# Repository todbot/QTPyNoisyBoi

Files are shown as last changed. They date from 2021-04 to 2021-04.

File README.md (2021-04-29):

# QTPyNoisyBoi

## QTPy/XIAO-based noisy 3-channel CV modulator Eurorack synth module

This is a bad idea.

It has:
- 3 CV outputs
- 1 gate input
- 3 knobs (next to outputs)
- 3 Neopixels (next to outputs)
- 2 tap buttons
- 1 neopixel on QT Py

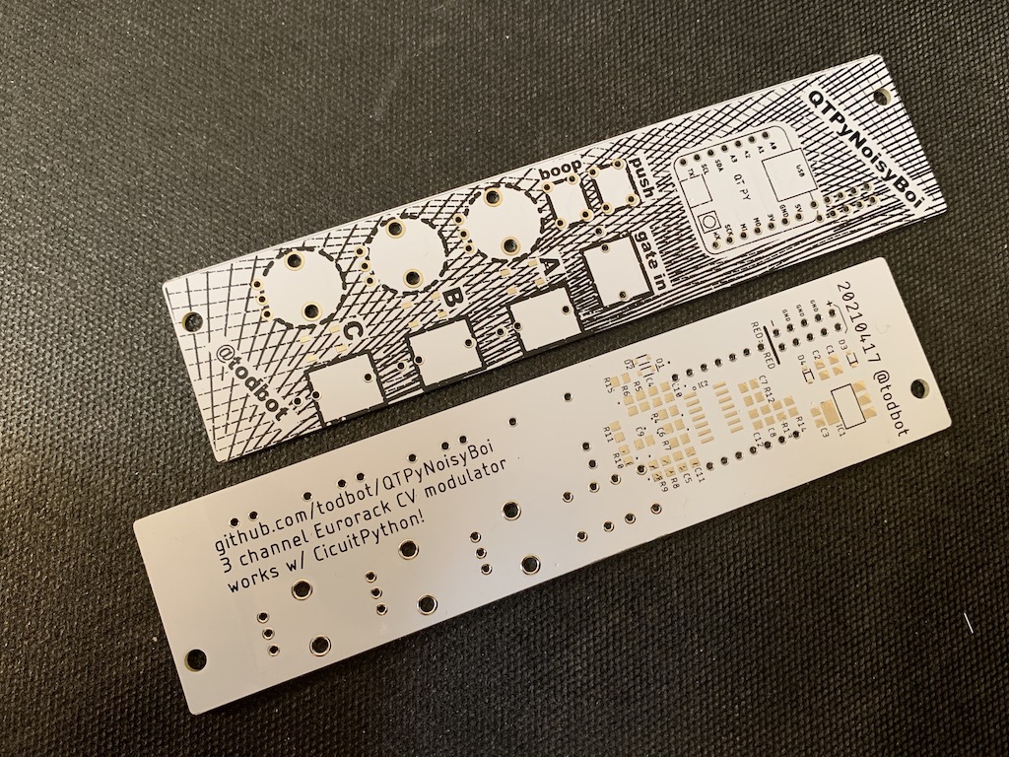
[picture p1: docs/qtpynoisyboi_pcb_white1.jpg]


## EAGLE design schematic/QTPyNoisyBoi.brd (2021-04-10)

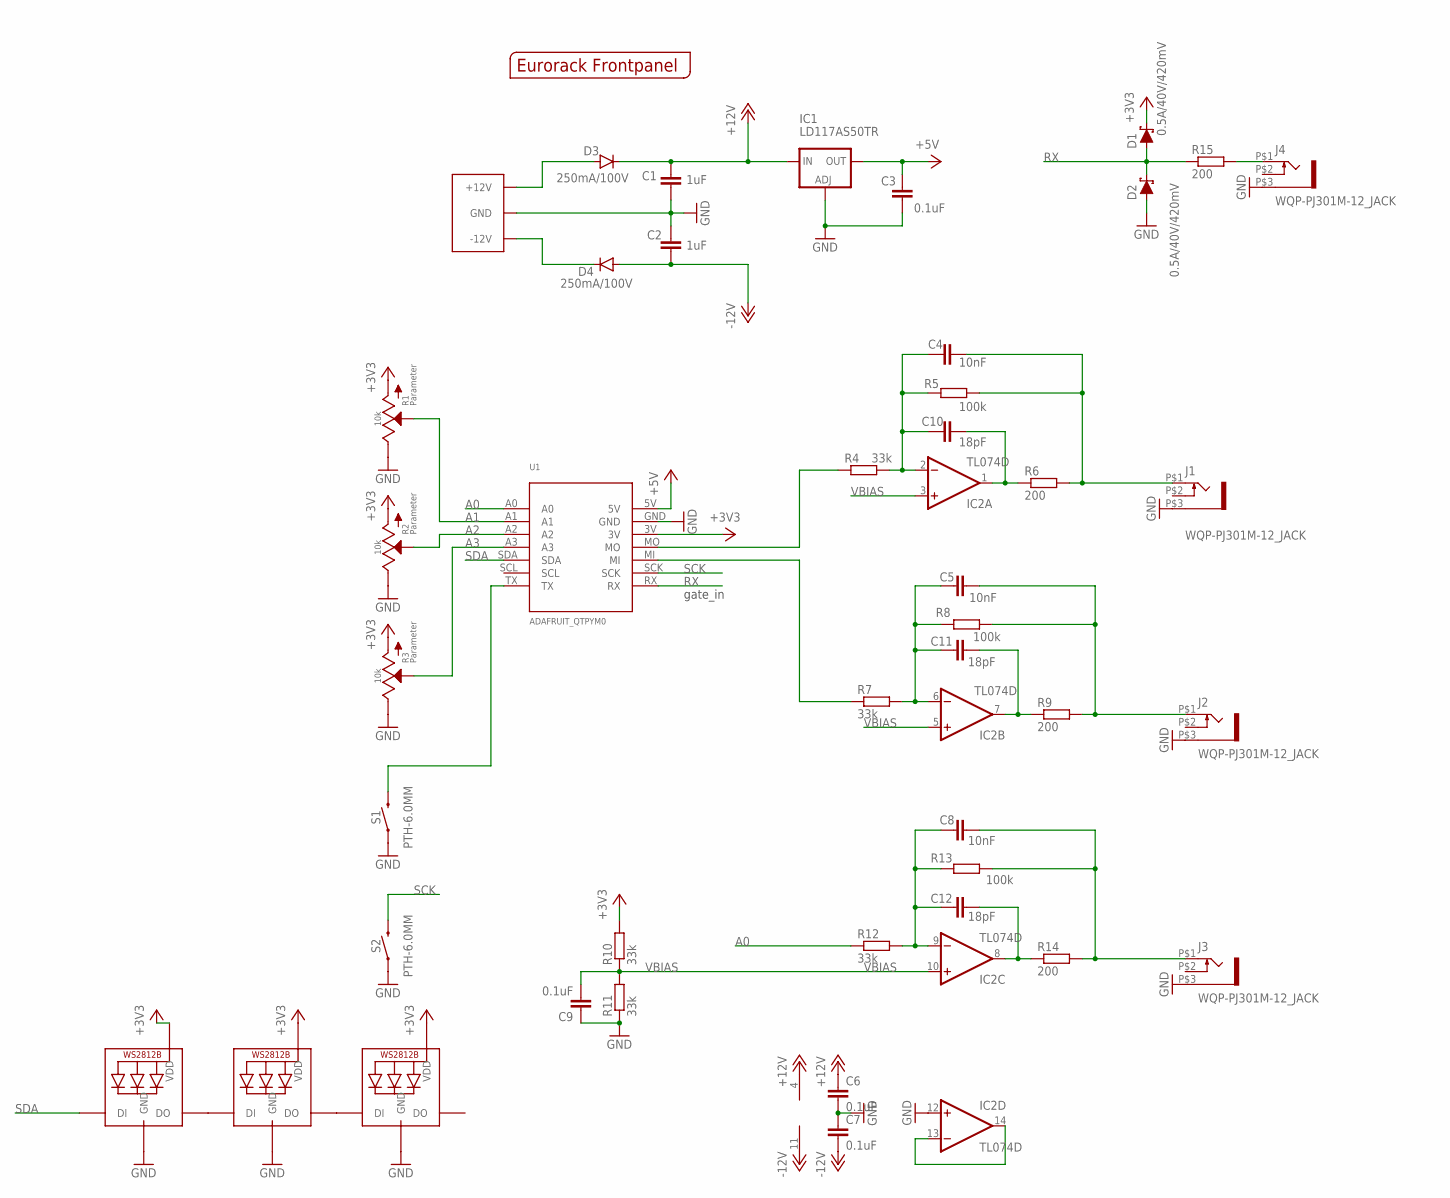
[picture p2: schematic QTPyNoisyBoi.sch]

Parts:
C1, C2: 1uF; C0805
C3, C6, C7, C9: 0.1uF; C0805
C4, C5, C8: 10nF; C0805
C10, C11, C12: 18pF; C0805
D1, D2: 0.5A/40V/420mV; SOD-323
D3, D4: 250mA/100V; SOD-323
DIM1: EURO_POWER_LOCKSKINNY; EURO_POWER_HEADER
IC1: LD117AS50TR; SOT223
IC2: TL074D; SO14
J1, J2, J3, J4: WQP-PJ301M-12_JACK
LED1, LED2, LED3: WS2812B5050; WS2812B
R1, R2, R3: 10k; OG-POTS_ALPS_POT_VERTICAL
R4, R7, R10, R11, R12: 33k; R0805
R5, R8, R13: 100k; R0805
R6, R9, R14, R15: 200; R0805
S1, S2: PTH-6.0MM; TACTILE_SWITCH_PTH_6.0MM
U1: ADAFRUIT_QTPYM0; ADAFRUIT_QTPY_M0
U$1: EURORACK_PANEL6HP; EURORACK6HPPANEL

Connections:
+3V3: D1.C, LED1.1-VDD (VDD), LED2.1-VDD (VDD), LED3.1-VDD (VDD), R1.P$3 (A), R2.P$3 (A), R3.P$3 (A), R10.2, U1.3V
+5V: C3.2, IC1.4 (OUT), U1.5V
+12V: C1.2, C6.1, D3.C, IC1.3 (IN), IC2.4 (V+)
-12V: C2.1, C7.2, D4.A, IC2.11 (V-)
A0: R12.1, U1.A0
A1: R1.P$2 (S), U1.A1
A2: R2.P$2 (S), U1.A2
A3: R3.P$2 (S), U1.A3
GND: C1.1, C2.2, C3.1, C6.2, C7.1, C9.1, D2.A, DIM1.3 (GND), DIM1.4 (GND), DIM1.5 (GND), DIM1.6 (GND), DIM1.7 (GND), DIM1.8 (GND), IC1.1 (ADJ), IC2.12 (+IN), J1.P$3 (1), J2.P$3 (1), J3.P$3 (1), J4.P$3 (1), LED1.3-GND (GND), LED2.3-GND (GND), LED3.3-GND (GND), R1.P$1 (E), R2.P$1 (E), R3.P$1 (E), R11.1, S1.1, S2.1, U1.GND
unnamed: C5.2, J2.P$1 (2), R8.2, R9.2
unnamed: S1.3 (2), U1.TX
unnamed: C12.2, IC2.8 (OUT), R14.1
unnamed: C8.1, C12.1, IC2.9 (-IN), R12.2, R13.1
unnamed: J4.P$1 (2), R15.2
unnamed: R4.1, U1.MO
unnamed: R7.1, U1.MI
unnamed: IC2.13 (-IN), IC2.14 (OUT)
unnamed: C4.2, J1.P$1 (2), R5.2, R6.2
unnamed: C4.1, C10.1, IC2.2 (-IN), R4.2, R5.1
unnamed: C8.2, J3.P$1 (2), R13.2, R14.2
unnamed: D4.C, DIM1.1 (-12V), DIM1.2 (-12V)
unnamed: C5.1, C11.1, IC2.6 (-IN), R7.2, R8.1
unnamed: C11.2, IC2.7 (OUT), R9.1
unnamed: LED1.2-DOUT (DO), LED2.4-DIN (DI)
unnamed: LED2.2-DOUT (DO), LED3.4-DIN (DI)
unnamed: D3.A, DIM1.9 (+12V), DIM1.10 (+12V)
unnamed: C10.2, IC2.1 (OUT), R6.1
RX: D1.A, D2.C, R15.1, U1.RX
SCK: S2.3 (2), U1.SCK
SDA: LED1.4-DIN (DI), U1.SDA
VBIAS: C9.2, IC2.3 (+IN), IC2.5 (+IN), IC2.10 (+IN), R10.1, R11.2

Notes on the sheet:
gate_in

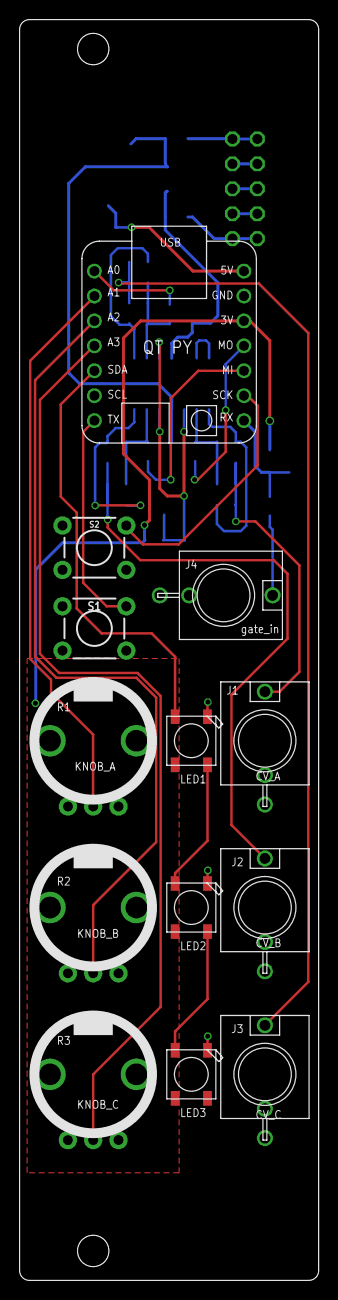
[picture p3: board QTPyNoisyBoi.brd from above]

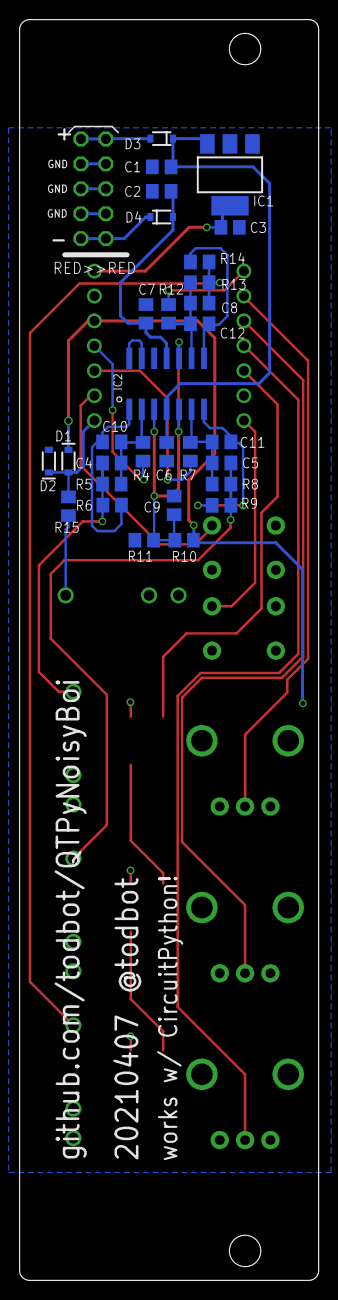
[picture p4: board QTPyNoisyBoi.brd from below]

Board: 2 copper layers, 30.5 x 128.5 mm, 45 parts (31 on the bottom side), 31 nets.

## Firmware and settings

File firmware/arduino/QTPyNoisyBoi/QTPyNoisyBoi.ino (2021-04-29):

/*
 * QTPyNoisyBoi  -- 3 Channel CV modulator for Eurorack modular synths
 *
 * 2021 - Tod Kurt / @todbot - github.com/todbot/qtpynoisyboi
 * 
 * # MOSI -- out A (PWM)  -- Arduino pin 10
 * # MISO -- out B (PWM)  -- Arduino pin 9
 * # A0   -- out C (DAC)  -- Arduino pin 0
 * # RX   -- gate in      -- Arduino pin 7
 * # A1   -- knob in  A   -- Arduino pin 1
 * # A2   -- knob in  B   -- Arduino pin 2
 * # A3   -- knob in  C   -- Arduino pin 3
 * # TX   -- button 1     -- Arduino pin 6
 * # SCK  -- button 2     -- Arduino pin 8
 *
 * Depends on the following:
 * - Adafruit SAMD boards BSP
 * - Bounce2 library: https://github.com/thomasfredericks/Bounce2
 * - 
 * 
 *
 */

#include <Bounce2.h>

// Hmm, Seeed's pwm() function is awesome but glitchy
// I think because it's flipping the prescaler or changing without
// waiting for TCC ready?
// So for now I'll use this semi-homegrown 'analogWriteHF()' func
//#include "wiring_pwm.h"
#include "analogWriteHF.h"
#include "VoltageOut.h"
#include "calibration.h"

int outAPin = 10; // MOSI on QTPY  (TCC1)
int outBPin = 9;  // MISO on QTPY  (TCC0)
int outCPin = 0;  // A0 on QTPY

int gateInPin = 7; // RX on QTPY

int knobAPin = 1;  // A1 on QTPY
int knobBPin = 2;  // A2 on QTPY
int knobCPin = 3;  // A3 on QTPY

int but1Pin = 6;   // TX on QTPY
int but2Pin = 8;   // RX on QTPY

const uint32_t pwm_freq = 11720; // 

VoltageOut voutA = VoltageOut(cals_a, sizeof(cals_a)/sizeof(voltage_calibration));
VoltageOut voutB = VoltageOut(cals_b, sizeof(cals_b)/sizeof(voltage_calibration));
VoltageOut voutC = VoltageOut(cals_c, sizeof(cals_c)/sizeof(voltage_calibration));

Bounce b1 = Bounce(); // Instantiate a Bounce object
Bounce b2 = Bounce(); // Instantiate a Bounce object

void setup()
{
    delay(1000);
    Serial.begin(115200);
    Serial.println("Hello from QTPyNoisyBoi!");
    pinMode(outAPin, OUTPUT);
    pinMode(outBPin, OUTPUT);
    pinMode(outCPin, OUTPUT);
    
    pinMode(gateInPin, INPUT_PULLDOWN);
    pinMode(knobAPin, INPUT);
    pinMode(knobBPin, INPUT);
    pinMode(knobCPin, INPUT);
    
    //pinMode(but1Pin, INPUT_PULLUP);
    //pinMode(but2Pin, INPUT_PULLUP);
    b1.attach(but1Pin, INPUT_PULLUP);
    b2.attach(but2Pin, INPUT_PULLUP);
}

float voltages[8] = {0.0, 1.0, 2.0, 3.0, 4.0, 5.0, 6.0, 0.0 };

uint8_t i=0;
uint32_t lastTime;
uint16_t updateTime = 500;

void loop()
{
    // read all inputs
    b1.update();
    b2.update();
    //gateIn.update();
    
    int knobAval = analogRead(knobAPin);
    int knobBval = analogRead(knobBPin);
    int knobCval = analogRead(knobCPin);
    
    if( b1.fell() ) {
        Serial.println("*** button 1 press!");
    }
    if ( b2.fell() ) {
        Serial.println("*** button 2 press!");
    }

    if( (millis() - lastTime) > updateTime ) {
        lastTime = millis();
        
        float v = voltages[i];
        uint32_t dacA_val = voutA.dac_for_voltage(v) / 64;
        uint32_t dacB_val = voutB.dac_for_voltage(v) / 64;
        uint32_t dacC_val = voutC.dac_for_voltage(v) / 64;

        Serial.printf("knobs: %3x %3x %3x \t", knobAval, knobBval, knobCval);
        Serial.printf("dac: %5d %5d %5d\n", dacA_val, dacB_val, dacC_val);
    
        analogWriteHF(outAPin, dacA_val );  // ranges 0-1023
        analogWriteHF(outBPin, dacB_val );  // ranges 0-1023
        analogWrite(outCPin, dacC_val );    // actually analog, 0-1023

        i = (i+1) % 8;
    }
}


/// testing

uint32_t dac_val = 512;  // 10-bit number

void loop0()
{
    //pwm(outAPin, pwm_freq, dac_val);  // ranges 0-1023
    //pwm(outBPin, pwm_freq, dac_val);  // ranges 0-1023
    analogWriteHF(outAPin, dac_val);  // ranges 0-1023
    analogWriteHF(outBPin, dac_val);  // ranges 0-1023
    analogWrite(outCPin, dac_val);    // actually analog, 0-1023
    //dac_val++;
    if( dac_val >= 1024 ) dac_val = 0;
    
    delay(5);
}

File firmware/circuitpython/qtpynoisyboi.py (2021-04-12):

# qtpynoisyboi_test.py --
#
# MOSI -- out A (PWM)
# MISO -- out B (PWM)
# A0   -- out C (DAC)
# RX   -- gate in 
# A1   -- knob in  A
# A2   -- knob in  B
# A3   -- knob in  C
# TX   -- button 1
# SCK  -- button 2

import time
import board
import neopixel
import pwmio
import analogio
import digitalio
from adafruit_debouncer import Debouncer
import random

import voltageio
import waveforms

do_calibration_setup = False

# determined experimentally
calibration = {
    "a": {
        -3.34: 65535,
        0.0: 43675,
        6.69:0,
    },
    "b": {
        -3.40: 65535,
        0.0: 43535,
        6.73: 0,
    },
    "c": {
        }
}

but1pin = digitalio.DigitalInOut(board.TX)
but1pin.pull = digitalio.Pull.UP
but1 = Debouncer(but1pin)
but2pin = digitalio.DigitalInOut(board.SCK)
but2pin.pull = digitalio.Pull.UP
but2 = Debouncer(but2pin)

knob_a = analogio.AnalogIn(board.A1)
knob_b = analogio.AnalogIn(board.A2)
knob_c = analogio.AnalogIn(board.A3)
        
out_a = pwmio.PWMOut(board.MOSI, frequency=25000, duty_cycle=0)
out_b = pwmio.PWMOut(board.MISO, frequency=25000, duty_cycle=0)
vout_a = voltageio.VoltageOut(calibration['a'])
vout_b = voltageio.VoltageOut(calibration['b'])

def set_out_a_duty(dc):
    out_a.duty_cycle = dc
def set_out_b_duty(dc):
    out_b.duty_cycle = dc
def set_out_a_volts(voltage):
    out_a.duty_cycle = vout_a.dac_for_voltage(voltage)
def set_out_b_volts(voltage):
    out_b.duty_cycle = vout_b.dac_for_voltage(voltage)

# calibration
if do_calibration_setup:
    print("Calibrate PWM DAC.")
    while True:
        print("Enter 'set_out_a_duty(65535)' and watch output on multimeter:")
        value = input().strip()
        eval(value)
        print('value:"',value,'"')
        time.sleep(0.1)
    


sin_wave = waveforms.Waveform('sin',steps=256)
rnd_wave = waveforms.Waveform('rnd',steps=16)

wave = sin_wave.wave
volt_offset = 0.0
volt_amplitude = 2.0
period = 1.0
dt = period / len(wave)

i=0
val = 0
wave_index=0
last_time = time.monotonic()

while True:
    but1.update()
    but2.update()
    period = utils.map_range(knob_a.value, 0,1023, 0.01, 10)
                             
    now = time.monotonic()
    if now > dt + last_time:
        last_time = now
        wave_index = (wave_index + 1) % len(wave)
        print("updated", wave_index)
    # get the wave value, scale it by amplitude and offsetit
    val = offset + amplitude * wave[wave_index]
    # convert to volts and send it out
    set_out_a_volts(val)
    

#note_volts = [0, 0.0833, 0.1666, 0.25, 0.333, 0.4166, 0.5, 0.5833, 0.6666, 0.75, 0.83333, 0.9166, 1]
#note_volts = [0,          0.1666, 0.25, 0.333,         0.5,         0.6666, 0.75, 0.83333, 1]
#note_vals = [1, 1.5, 2, 2.5]
#note_vals = [1, 2, 2.5, 3, 3.5, 4]

    #val = sin_wave.wave[i] # * amplitude
    #val = random.random() * 1
    #val = note_volts[random.randint(0,len(note_volts)-1)]
#    val = note_vals[j]
#    j = (j+1) % len(note_vals)

#j=0
    
# cvsa_index = 0
# cvsb_index = 2
# cvai=0
# cvbi=0
# cva_last = time.monotonic()
# cvb_last = time.monotonic()

# cvsa = cvs_list[cvsa_index]
# cvsb = cvs_list[cvsb_index]

# while True:
#     butt1.update()
#     now = time.monotonic()
#     if now > cva_last + rateA:
#         cva_last = now
#         cvai = (cvai + 1) % len(cvsa)
#         duty_cycle = int( cvsa[cvai] * 65535/100)
#         outA.duty_cycle = 65535 - duty_cycle
#     if now > cvb_last + rateB:
#         cvb_last = now
#         cvbi = (cvbi + 1) % len(cvsb)
#         duty_cycle = int( cvsb[cvbi] * 65535/100)
#         outB.duty_cycle = 65535 - duty_cycle
# #    rateA = 0.01 + (potAknob.value / 65535 / 2)
#     rateA = (potAknob.value / 65535 ) #/ len(cvsa))
#     rateB = 0.01 + (potBknob.value / 65535 / 2)
#     if butt1.fell: # pressed
#         print("push!")
#         cvsa_index = (cvsa_index + 1 ) % len(cvs_list)
#         cvsa = cvs_list[cvsa_index]
#         cvsai=0
        



# cv = 50
# while True:
#     duty_cycle = int(cv * 65535/100)
#     out1.duty_cycle = 65535 - duty_cycle
    
# cv_index = 0
# while True:
#     if but1.value == False: # pressed
#         print("push!")
#         cv_index = (cv_index + 1 ) % len(cvs_list)
#     cvs = cvs_list[ cv_index ]
    
#     for cv in cvs:
#         duty_cycle = int(cv * 65535/100)
#         out1.duty_cycle = 65535 - duty_cycle
#         out2.duty_cycle = duty_cycle
#         print("duty:",duty_cycle, out1.duty_cycle)
#         rate = 0.01 + (potAknob.value / 65535 / 2)
#         time.sleep(rate)
       

# # test knob to voltage output
# while True:
#     pos = potknob.value // 256
#     print("pos:",pos)
#     out1.duty_cycle = 65535 - potknob.value # inverting amplifier
#     time.sleep(0.01)


# # test simple triangle wave output
# i=0
# while True:
#     if i < 50:
#         out1.duty_cycle = int(i * 2 * 65535 / 100)  # Up
#     else:
#         out1.duty_cycle = 65535 - int((i - 50) * 2 * 65535 / 100)  # Down
#     i = (i + 1) % 100
#     time.sleep(0.001)
    
# while True:
#     for i in range(100):
#         if i < 50:
#             led.duty_cycle = int(i * 2 * 65535 / 100)  # Up
#         else:
#             out1.duty_cycle = 65535 - int((i - 50) * 2 * 65535 / 100)  # Down
# #        time.sleep(0.0001)

        

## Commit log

2021-03-24 added cap on vmidref; various cleanup
    [QTPyNoisyBoi.brd, QTPyNoisyBoi.sch]
2021-04-01 submit to fab
    [QTPyNoisyBoi.brd, QTPyNoisyBoi.sch]
2021-04-08 fix dumb +/- opamp input swap on B and C
    [QTPyNoisyBoi.brd, QTPyNoisyBoi.sch]
2021-04-08 added 2nd button
    [QTPyNoisyBoi.brd, QTPyNoisyBoi.sch]
2021-04-10 added neopixels, woorah
    [QTPyNoisyBoi.brd, QTPyNoisyBoi.sch]
2021-04-12 some progress
    [QTPyNoisyBoi.brd, QTPyNoisyBoi.sch]
2021-04-18 cleanup silkscreen
2021-04-28 moving to Arduino because CircuitPython has poor timing accuracy (but lovely PWM)
2021-04-28 added first cut at the calibration stuff
2021-04-29 more Arduino-way progress
2021-09-07 added PTH idea
    [QTPyNoisyBoi_PTH.sch]

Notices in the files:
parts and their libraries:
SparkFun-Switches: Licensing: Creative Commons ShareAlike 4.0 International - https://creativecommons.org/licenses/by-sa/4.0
